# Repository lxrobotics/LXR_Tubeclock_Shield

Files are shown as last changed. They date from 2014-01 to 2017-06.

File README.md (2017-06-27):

LXRobotics P4 TubeClockShield
==============



# Image

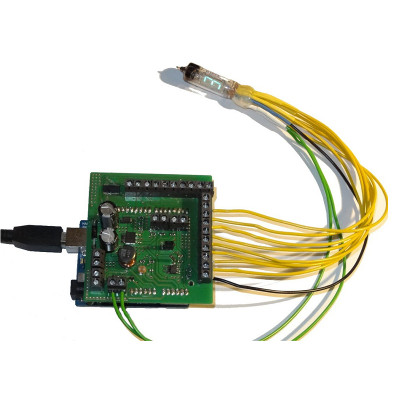
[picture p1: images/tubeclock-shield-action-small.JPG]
LXRobotics P4 Tubeclock Shield


# Description

A Tube Clock is defined as a clock showing the time on a so-called Vacuum Fluorescent Display (VFD). The exact operation of VFDs is described on Wikipedia vividly. The VFDs were developed in the 1960s in Japan and replaced the Nixie tubes which were functioning based on glow lamps principle. Today VFDs, because of their retro looks, are primarily used by hobbyists for clocks construction and other electronic projects. The LXRobotics Tubeclock Shield allows, in combination with an Arduino Uno Board, the construction of such tube clock. For the quick start, Arduino libraries are available with sample programs.

**Features**

* Tube voltage adjustable from 30 to 70 V
* I2C-Real Time Clock  (RTC) for clock functionality
* Brightness sensor (LDR =Light Dependent Resistor)
* Temperature sensor (NTC-Thermistor)
* Connections for 2 button/switch
* Connection for external backup baterry for keeping the current time also at power failure (external backup battery is not included in the delivery)
* Exclusively screw terminals for simple yet stable connection of cables to the board available
* Arduino Library available for control of Tubeclock Shield with example programms
* Arduino Library available for the usage of Tubeclock Shield with a IV-18 Tube
* Arduino Library for conversion of the temperature sensor - tube data in °C

# Videos

VIDEO1 (https://www.youtube.com/watch?v=TnZkssseJw4 "LXRobotics Tubeclock Shield")

VIDEO2 (https://www.youtube.com/watch?v=x0OO6zDt8ZQ "LXRobotics Tubeclock Shield IV-18 Demo")

VIDEO3 (https://www.youtube.com/watch?v=44m70J2q8iM "LXRobotics Tubeclock Shield IV-6 Demo")

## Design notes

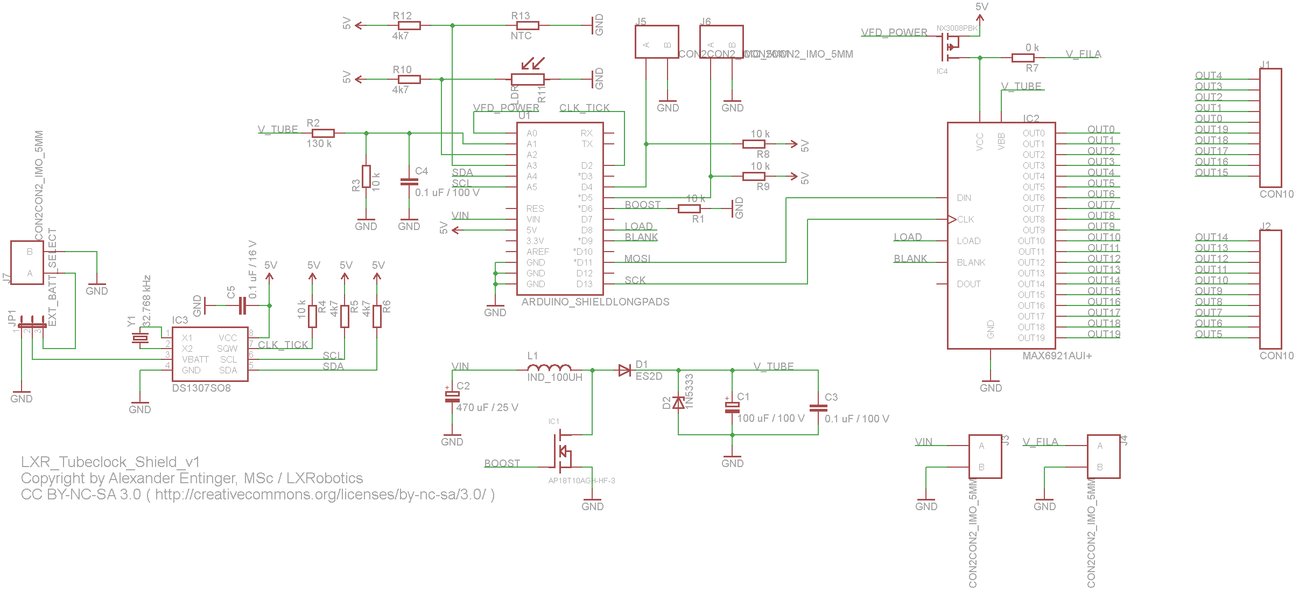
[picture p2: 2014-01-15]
hardware/lxr_tubeclock_shield_v1.png

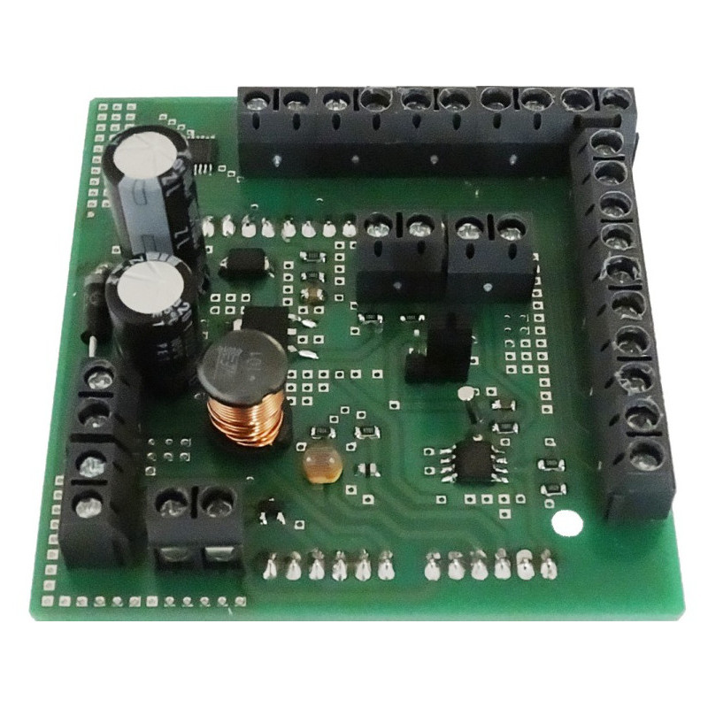
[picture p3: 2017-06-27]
images/tubeclock-shield-side-large.jpg

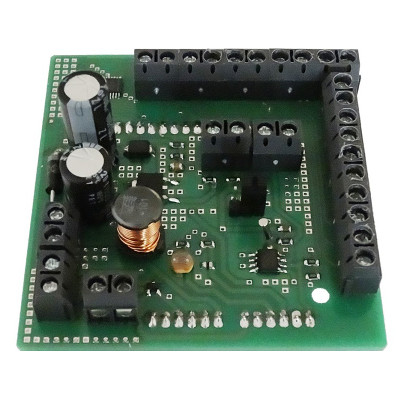
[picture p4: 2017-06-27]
images/tubeclock-shield-side-small.jpg

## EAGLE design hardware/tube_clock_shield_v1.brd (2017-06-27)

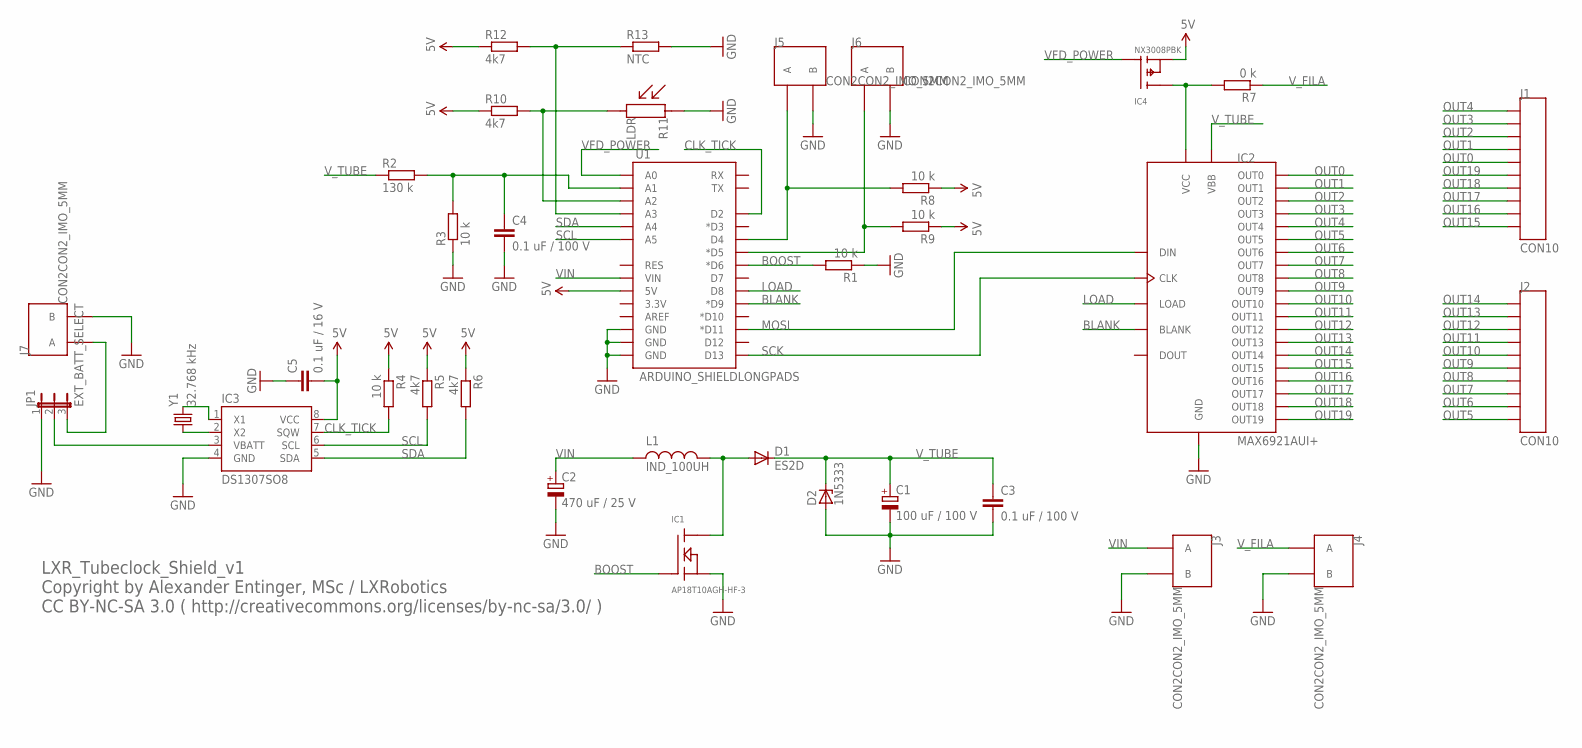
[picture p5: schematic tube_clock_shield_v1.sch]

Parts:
C1: 100 uF / 100 V; E5-10,5
C2: 470 uF / 25 V; E5-10,5
C3, C4: 0.1 uF / 100 V; C0805
C5: 0.1 uF / 16 V; C0805
D1: ES2D; SMB
D2: 1N5333; C1702-15
IC1: AP18T10AGH-HF-3; TO252
IC2: MAX6921AUI+; TSSOP28
IC3: DS1307SO8; SO08
IC4: NX3008PBK; SOT23
J1, J2: CON10
J3, J4, J5, J6, J7: CON2CON2_IMO_5MM; CON2_IMO
JP1: EXT_BATT_SELECT; JP2
L1: IND_100UH; LEISTUNGS_INDUKTIVITAET_PACKAGE
R1, R3, R4, R8, R9: 10 k; R0805
R2: 130 k; R0805
R5, R6, R10, R12: 4k7; R0805
R7: 0 k; R0805
R11: LDR
R13: NTC; R0805
U1: ARDUINO_SHIELDLONGPADS; DUEMILANOVE_SHIELD_LONGPADS
Y1: 32.768 kHz; TC26HEZ

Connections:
5V: C5.2, IC3.8 (VCC), IC4.2 (S), R4.1, R5.1, R6.1, R8.1, R9.1, R10.1, R12.1, U1.5V
BLANK: IC2.20 (BLANK), U1.D9 (*D9)
BOOST: IC1.G, R1.2, U1.D6 (*D6)
CLK_TICK: IC3.7 (SQW), R4.2, U1.D2
EXT_BATT: J7.P$1 (A), JP1.3
GND: C1.-, C2.-, C3.2, C4.2, C5.1, D2.A, IC1.S, IC2.21 (GND), IC3.4 (GND), J3.P$2 (B), J4.P$2 (B), J5.P$2 (B), J6.P$2 (B), J7.P$2 (B), JP1.1, R1.1, R3.1, R11.P$1, R13.2, U1.GND@0 (GND), U1.GND@1 (GND), U1.GND@2 (GND)
LOAD: IC2.23 (LOAD), U1.D8
MOSI: IC2.6 (DIN), U1.D11 (*D11)
unnamed: D1.A, IC1.D, L1.P$2
unnamed: C4.1, R2.2, R3.2, U1.A1
unnamed: IC3.2 (X2), Y1.1
unnamed: IC3.1 (X1), Y1.2
unnamed: IC2.7 (VCC), IC4.3 (D), R7.2
unnamed: J6.P$1 (A), R9.2, U1.D5 (*D5)
unnamed: IC3.3 (VBATT), JP1.2
unnamed: J5.P$1 (A), R8.2, U1.D4
unnamed: R10.2, R11.P$2, U1.A2
unnamed: R12.2, R13.1, U1.A3
OUT0: IC2.5 (OUT0), J1.P$5
OUT1: IC2.4 (OUT1), J1.P$4
OUT2: IC2.3 (OUT2), J1.P$3
OUT3: IC2.2 (OUT3), J1.P$2
OUT4: IC2.1 (OUT4), J1.P$1
OUT5: IC2.28 (OUT5), J2.P$10
OUT6: IC2.27 (OUT6), J2.P$9
OUT7: IC2.26 (OUT7), J2.P$8
OUT8: IC2.25 (OUT8), J2.P$7
OUT9: IC2.24 (OUT9), J2.P$6
OUT10: IC2.19 (OUT10), J2.P$5
OUT11: IC2.18 (OUT11), J2.P$4
OUT12: IC2.17 (OUT12), J2.P$3
OUT13: IC2.16 (OUT13), J2.P$2
OUT14: IC2.15 (OUT14), J2.P$1
OUT15: IC2.14 (OUT15), J1.P$10
OUT16: IC2.13 (OUT16), J1.P$9
OUT17: IC2.12 (OUT17), J1.P$8
OUT18: IC2.11 (OUT18), J1.P$7
OUT19: IC2.10 (OUT19), J1.P$6
SCK: IC2.22 (CLK), U1.D13
SCL: IC3.6 (SCL), R5.2, U1.A5
SDA: IC3.5 (SDA), R6.2, U1.A4
VFD_POWER: IC4.1 (G), U1.A0
VIN: C2.+, J3.P$1 (A), L1.P$1, U1.VIN
V_FILA: J4.P$1 (A), R7.1
V_TUBE: C1.+, C3.1, D1.C, D2.C, IC2.8 (VBB), R2.1

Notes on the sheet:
LXR_Tubeclock_Shield_v1 Copyright by Alexander Entinger, MSc / LXRobotics CC BY-NC-SA 3.0 ( http://creativecommons.org/licenses/by-nc-sa/3.0/ )

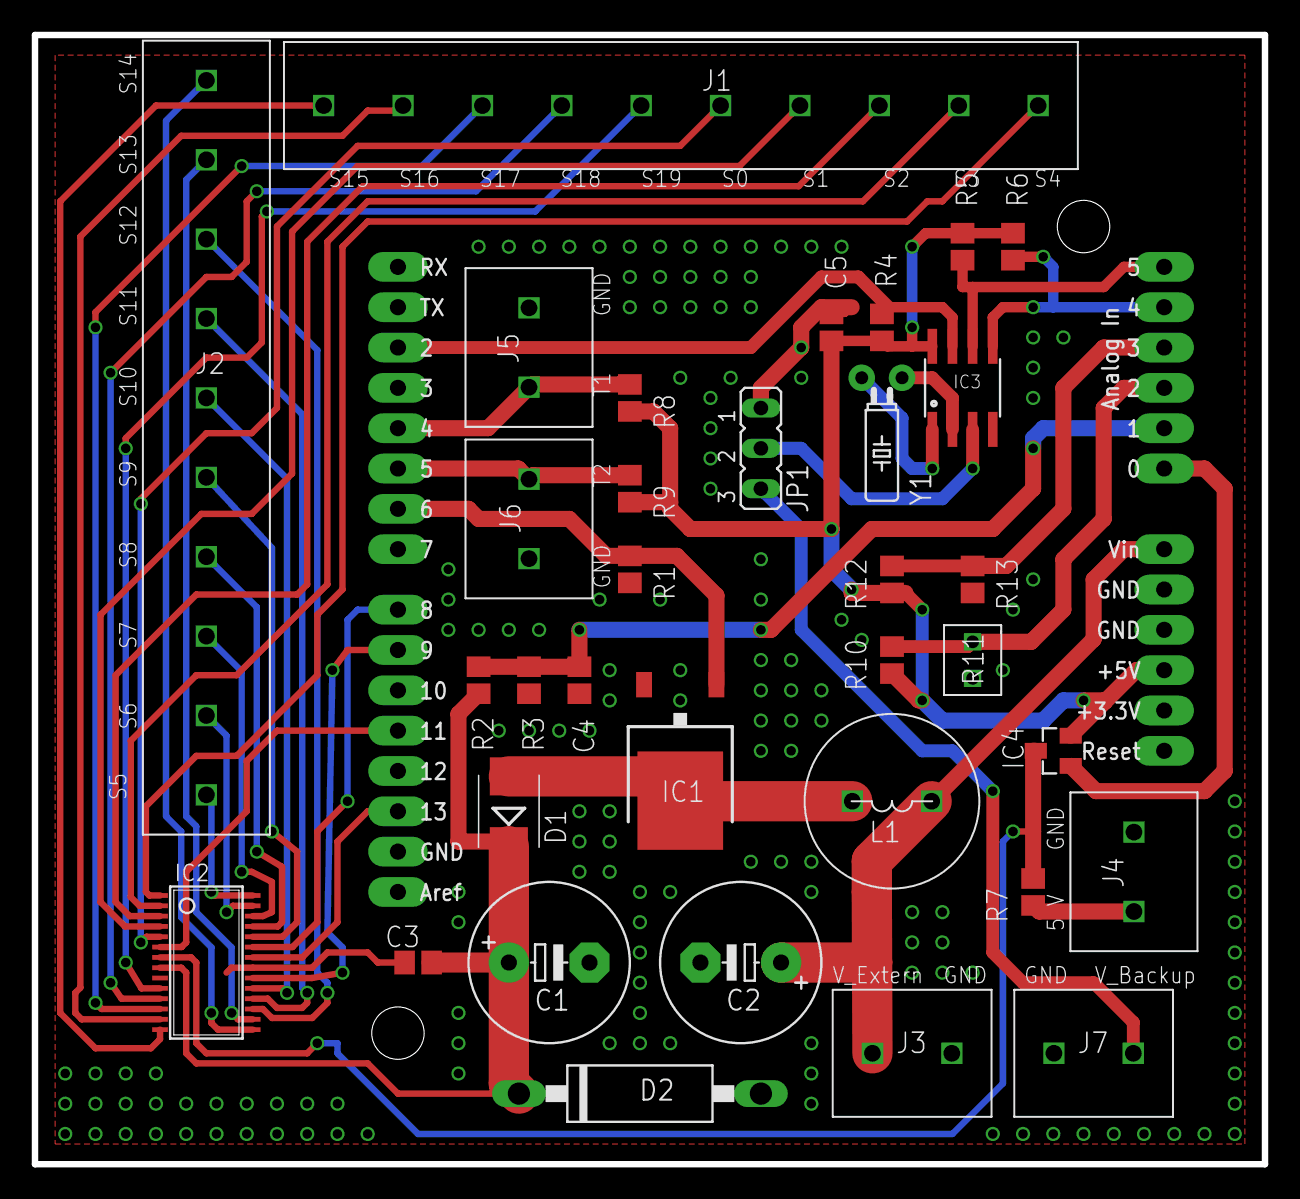
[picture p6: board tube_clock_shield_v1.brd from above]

Board: 2 copper layers, 77.5 x 71.1 mm, 35 parts (0 on the bottom side), 45 nets.

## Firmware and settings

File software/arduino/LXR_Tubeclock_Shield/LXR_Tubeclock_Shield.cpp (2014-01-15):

/**
 * @author Alexander Entinger, MSc / LXRobotics
 * @brief this file implements the control interface for the LXRobotics Tubeclock Shield
 * @file LXR_Tubeclock_Shield.cpp
 * @license Attribution-NonCommercial-ShareAlike 3.0 Unported (CC BY-NC-SA 3.0) ( http://creativecommons.org/licenses/by-nc-sa/3.0/ ) 
 */

#include "LXR_Tubeclock_Shield.h"

#include <avr/io.h>
#include <avr/interrupt.h>
#include <util/delay.h>

/* DEFINES */

// BOOST = D6 = PD6 = OC0A
#define BOOST_DDR	        (DDRD)
#define BOOST_PORT	        (PORTD)
#define BOOST		        (1<<6)
// VFD_POWER = A0 = ADC0 = PC0
#define VFD_POWER_DDR	        (DDRC)
#define VFD_POWER_PORT	        (PORTC)
#define VFD_POWER		(1<<0)
// BLANK = D9 = PB1
#define BLANK_DDR		(DDRB)
#define BLANK_PORT		(PORTB)
#define BLANK			(1<<1)
// LOAD = D8 = PB0
#define LOAD_DDR		(DDRB)
#define LOAD_PORT		(PORTB)
#define LOAD			(1<<0)
// SCK = D12 = PB5
#define SCK_DDR			(DDRB)
#define SCK			(1<<5)
// MOSI = D11 = PB3
#define MOSI_DDR		(DDRB)
#define MOSI			(1<<3)
// SS = D10 = PB2 // needs to be set to output to ensure safe spi operation
#define SS_DDR			(DDRB)
#define SS_PORT			(PORTB)
#define SS			(1<<2)
// T1 = D4 = PD4 = PCINT20
#define T1_DDR                  (DDRD)
#define T1_PORT                 (PORTD)
#define T1_PIN                  (PIND)
#define T1                      (1<<4)
// T2 = D5 = PD5 = PCINT21
#define T2_DDR                  (DDRD)
#define T2_PORT                 (PORTD)
#define T2_PIN                  (PIND)
#define T2                      (1<<5)

// filtered tube feedback voltage is connected with A1 = ADC1
#define TUBE_VOLTAGE_AS_ADC_INPUT \
ADMUX &= ~((1<<MUX3) | (1<<MUX2) | (1<<MUX1) | (1<<MUX0)); \
	ADMUX |= (1<<MUX0); 
// LDR is connected with A2 = ADC2
#define LDR_VOLTAGE_AS_ADC_INPUT \
ADMUX &= ~((1<<MUX3) | (1<<MUX2) | (1<<MUX1) | (1<<MUX0)); \
	ADMUX |= (1<<MUX1);
// NTC is connected with A3 = ADC3
#define NTC_VOLTAGE_AS_ADC_INPUT \
ADMUX &= ~((1<<MUX3) | (1<<MUX2) | (1<<MUX1)  | (1<<MUX0)); \
	ADMUX |= (1<<MUX1) | (1<<MUX0);

static volatile uint16_t m_tube_voltage = 0;
static volatile uint16_t m_ldr_voltage = 0;
static volatile uint16_t m_ntc_voltage = 0;
static volatile button_callback m_button_callback_func[2] = {
  0,0};

/* GLOBAL FUNCTIONS */

/** 
 * @brief initializes the tube clock shield module
 */
void LXR_Tubeclock_Shield::begin() {
  ADMUX = 0x00; 
  ADCSRA = 0x00; 
  ADCSRB = 0x00;
  // select AVCC as reference voltage, external capacitor at AREF pin
  ADMUX |= (1<<REFS0); 
  ADMUX &= ~(1<<REFS1);
  // disable digital input on ADC1 (tube) and ADC0 (LDR)
  //DIDR0 |= (1<<ADC0D) | (1<<ADC1D);
  // select adc input
  TUBE_VOLTAGE_AS_ADC_INPUT;	
  // enable all prescaler bits => prescaler = 128 => f_ADC = 125 kHz
  ADCSRA |= (1<<ADPS2) | (1<<ADPS1) | (1<<ADPS0);
  // enable auto trigger
  ADCSRA |= (1<<ADATE);
  // select auto trigger source : timer 0 overflow
  ADCSRB |= (1<<ADTS2);
  // enable the adc interrupt
  ADCSRA |= (1<<ADIE);
  // enable the adc
  ADCSRA |= (1<<ADEN);

  // set boost as output and to low
  BOOST_PORT &= ~BOOST;
  BOOST_DDR |= BOOST;

  // set timer 0 to phase correct pwm mode, timer mode 1, TOP = 0xFF
  TCCR0A = (1<<WGM00);
  // reset the timer value
  TCNT0 = 0;
  // reset TIMSK0 since its set by the great arduino ide
  TIMSK0 = 0x00;
  // set OCR0A
  OCR0A = 0;

  // VFD_POWER to output and high (power supply to maxim and v_fila cut off)
  VFD_POWER_PORT |= VFD_POWER;
  VFD_POWER_DDR |= VFD_POWER;

  // BLANK to output and high (all segments are blanked)
  BLANK_PORT |= BLANK;
  BLANK_DDR |= BLANK;

  // LOAD to output and low (latches hold their data)
  LOAD_PORT &= ~LOAD;
  LOAD_DDR |= LOAD;

  // init spi as master, max spi clk for MAX6921 according to datasheet = 5 MHz (Period = 200 ns)
  PRR &= ~(1<<PRSPI); // ensure that the spi power supply is turned on
  SCK_DDR |= SCK; 
  MOSI_DDR |= MOSI; 
  SS_DDR |= SS; 
  SS_PORT |= SS; // turn the spi pin direction to outputs
  SPCR = (1<<SPE) | (1<<MSTR) | (1<<SPR0); // enable spi in master mode, fSPI = fOSC/16 = 1 MHz

  // select T1 and T2 as inputs withput pullups (external pullups available
  T1_PORT &= ~T1;
  T1_DDR &= ~T1;
  T2_PORT &= ~T2;
  T2_DDR &= ~T2;
  // enable pin change interrupts on PD4 (PCINT20) and PD5 (PCINT21)
  PCMSK2 |= (1<<PCINT20) | (1<<PCINT21);
  // enable pin change interrupt 
  PCICR |= (1<<PCIE2);

}

/** 
 * @brief returns the voltage at the ldr resistor as determined by the adc
 */
uint16_t LXR_Tubeclock_Shield::get_ldr_voltage() {
  return m_ldr_voltage;
}

/** 
 * @brief returns the voltage at the ntc resistor as determined by the adc
 */
uint16_t LXR_Tubeclock_Shield::get_ntc_voltage() {
  return m_ntc_voltage;
}

/**
 * @brief registers a callback function which is called when the selected button is pressed, the registered function runs in isr context and therefor needs to be short and under no circumstances blocking
 */
void LXR_Tubeclock_Shield::register_button_callback(E_BUTTON_SELECT const sel, button_callback cb) {
  m_button_callback_func[sel] = cb;
}

static uint8_t prev_t1 = 1;
static uint8_t prev_t2 = 1;
/**
 * @brief interrupt service handler for pressed buttons
 */
ISR(PCINT2_vect) {
  uint8_t const t1_now = ((T1_PIN & T1) > 0) ? 1 : 0;
  uint8_t const t2_now = ((T2_PIN & T2) > 0) ? 1 : 0;
  if(prev_t1 == 1 && t1_now == 0) { // button 1 pressed
    if(m_button_callback_func[BUTTON1] != 0) m_button_callback_func[BUTTON1]();
  }
  if(prev_t2 == 1 && t2_now == 0) { // button 2 pressed
    if(m_button_callback_func[BUTTON2] != 0) m_button_callback_func[BUTTON2]();
  }
  prev_t1 = t1_now;
  prev_t2 = t2_now;
}

/** 
 * @brief sets the output voltage of the step-up-converter
 * @param volt voltage to be set
 */
void LXR_Tubeclock_Shield::set_tube_voltage(uint8_t const volt) {
  // adc input voltage divider divides by 14 - max voltage 70 Volt -> 5 V at ADC Input
  // weve got 10 bit precision, therefor 1024 Steps, 70 V => 1024, 35 V = > 512, 0 V => 0
  if(volt <= MAX_TUBE_VOLTAGE) {
    uint32_t const multiplied_voltage = (uint32_t)(volt) << 10; // multiplication by 1024
    m_tube_voltage = (uint16_t)(multiplied_voltage / (uint32_t)(MAX_TUBE_VOLTAGE+1)); // division by 70 results in the 10 bit value representing the desired voltage on the adc pin
  }	
}

/** 
 * @brief enables the tube voltage
 */
void LXR_Tubeclock_Shield::enable_tube_voltage() {
  // reset ocr0a
  OCR0A = 0;
  // clear on compare match when counting up, set on compare match when counting down
  TCCR0A &= ~(1<<COM0A0); 
  TCCR0A |= (1<<COM0A1);
  // activate timer with prescaler 1 => f_PWM = 62.5 kHz
  TCCR0B = (1<<CS01);
}

/** 
 * @brief disables the tube voltage
 */
void LXR_Tubeclock_Shield::disable_tube_voltage() {
  // deactivate the timer	
  TCCR0B &= ~((1<<CS02) | (1<<CS01) | (1<CS00));
  // disconnect OC0A from timer logic
  TCCR0A &= ~((1<<COM0A0) | (1<<COM0A1));
  // set OC0A output to low
  BOOST_PORT &= ~BOOST;
}
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

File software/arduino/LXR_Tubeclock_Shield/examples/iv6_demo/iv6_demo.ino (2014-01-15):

/** 
 * @author Alexander Entinger MSc, LXRobotics
 * @brief this file demonstrates how to use the LXR_Tubeclock_Shield library to control a IV6 tube
 * @file iv6_demo.ino
 * @license Attribution-NonCommercial-ShareAlike 3.0 Unported (CC BY-NC-SA 3.0) ( http://creativecommons.org/licenses/by-nc-sa/3.0/ )
 */

#include "LXR_Tubeclock_Shield.h"
#include <util/delay.h> // for _delay_ms, dont use delay here, since it needs timer 0 and the tube clock shields needs that too

void setup() {
  // initialize the tube clock shield
  LXR_Tubeclock_Shield::begin(); 
  // set the tube voltage to 25 V
  LXR_Tubeclock_Shield::set_tube_voltage(25);
  // enable the tube voltage generation
  LXR_Tubeclock_Shield::enable_tube_voltage();
  // enable the vfd controller
  LXR_Tubeclock_Shield::enable_vfd_controller();
  // write 0 to all segments
  s_segment_map seg_map; 
  seg_map.all = 0;
  LXR_Tubeclock_Shield::vfd_controller_write(seg_map);
  // load the written data into the display latches, a write command always goes in combination with a load command, otherwise the written information is not stored
  LXR_Tubeclock_Shield::vfd_controller_load();
  // disable the blank so that the written data can be shown - since all digits are off the display is blank
  LXR_Tubeclock_Shield::vfd_controller_blank_off();	
}

void loop() {
  for(uint8_t digit_value = 0; digit_value <= 10; digit_value++) {
    iv6_set_digit(digit_value);
    _delay_ms(250); 
  }
}

// defines 
#define DP		(1<<0)
#define A		(1<<1)
#define B		(1<<2)
#define C		(1<<3)
#define D		(1<<4)
#define E		(1<<5)
#define F		(1<<6)
#define G		(1<<7)
#define	DIG_NUM_0	(A | B | C | D | E | F)
#define	DIG_NUM_1	(B | C)
#define DIG_NUM_2       (A | B | G | E | D)
#define DIG_NUM_3	(A | B | C | D | G)
#define DIG_NUM_4	(B | C | F | G)
#define DIG_NUM_5	(A | F | G | C | D)
#define DIG_NUM_6	(A | F | E | D | C | G)
#define DIG_NUM_7	(A | B | C)
#define DIG_NUM_8	(A | B | C | D | E | F | G)
#define DIG_NUM_9	(A | B | C | D | G | F)
#define DIG_BLANK	(0)

// global variables
static volatile uint8_t const digit_map[] = {
  DIG_NUM_0, DIG_NUM_1, DIG_NUM_2, DIG_NUM_3, DIG_NUM_4, DIG_NUM_5, DIG_NUM_6, DIG_NUM_7, DIG_NUM_8, DIG_NUM_9, DIG_BLANK
}; 

/** 
 * @brief this function sets a digit of the iv 6 module
 * @param val value for the digit to display
 */
void iv6_set_digit(uint8_t const val) {
  s_segment_map map;
  map.all = 0;
  // set the lines properly
  // activate grid
  map.segment.segOUT4 = 1;
  // activate segments depending on the digit 
  if(digit_map[val] & DP) map.segment.segOUT2 = 1; 
  else map.segment.segOUT2 = 0;
  if(digit_map[val] & A) map.segment.segOUT0 = 1; 
  else map.segment.segOUT0 = 0;
  if(digit_map[val] & B) map.segment.segOUT1 = 1; 
  else map.segment.segOUT1 = 0;
  if(digit_map[val] & C) map.segment.segOUT3 = 1; 
  else map.segment.segOUT3 = 0;
  if(digit_map[val] & D) map.segment.segOUT16 = 1; 
  else map.segment.segOUT16 = 0;
  if(digit_map[val] & E) map.segment.segOUT17 = 1; 
  else map.segment.segOUT17 = 0;
  if(digit_map[val] & F) map.segment.segOUT18 = 1; 
  else map.segment.segOUT18 = 0;
  if(digit_map[val] & G) map.segment.segOUT19 = 1; 
  else map.segment.segOUT19 = 0;
  // write the data to the vfd controller	
  LXR_Tubeclock_Shield::vfd_controller_write(map);
  // load the data to the output latches
  LXR_Tubeclock_Shield::vfd_controller_load();
}

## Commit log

2014-01-15 initial checkin of brushless motorshield
2017-06-27 Adding hardware and images
    [tube_clock_shield_v1.brd, tube_clock_shield_v1.sch]

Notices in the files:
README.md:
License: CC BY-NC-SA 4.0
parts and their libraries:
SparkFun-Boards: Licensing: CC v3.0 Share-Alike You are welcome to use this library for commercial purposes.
